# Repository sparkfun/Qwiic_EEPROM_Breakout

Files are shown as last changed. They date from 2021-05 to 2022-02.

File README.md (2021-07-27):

Qwiic EEPROM - 512Kbit
=======================================

Qwiic EEPROM

[*Qwiic EEPROM - 512Kbit (COM-18355)*](https://www.sparkfun.com/products/18355)

A simple breakout for the 512kbit common I2C EEPROMs.

Repository Contents
-------------------

* **/Hardware** - Eagle design files (.brd, .sch)
* **/Firmware** - EEPROM test sketch

Documentation
------------

* **[SparkFun External EEPROM Arduino Library](https://github.com/sparkfun/SparkFun_External_EEPROM_Arduino_Library)** - Arduino library for the Qwiic EEPROM - 512Kbit
* **[Qwiic EEPROM Python Package](https://github.com/sparkfun/Qwiic_EEPROM_Py)** - Python package for the Qwiic EEPROM - 512Kbit
* **[Datasheet CAT24C512](https://www.onsemi.com/pub/Collateral/CAT24C512-D.PDF)** - Datasheet for EEPROM part number 24512A
* **[Reading and Writing Serial EEPROMs](https://learn.sparkfun.com/tutorials/reading-and-writing-serial-eeproms)** - Tutorial
* **[Qwiic EEPROM Hookup Guide](https://learn.sparkfun.com/tutorials/1661)** - Hookup guide for the Qwiic EEPROM - 512Kbit

<!-- * **[Datasheet RM24C512C](https://cdn.sparkfun.com/assets/2/c/4/c/0/DS-RM24C512C_082.pdf)** - Datasheet for EEPROM part number 24512C -->

License Information
-------------------

This product is _**open source**_! 

Please review the LICENSE.md file for license information. 

If you have any questions or concerns on licensing, please contact technical support on our [SparkFun forums](https://forum.sparkfun.com/viewforum.php?f=152).

Distributed as-is; no warranty is given.

- Your friends at SparkFun.

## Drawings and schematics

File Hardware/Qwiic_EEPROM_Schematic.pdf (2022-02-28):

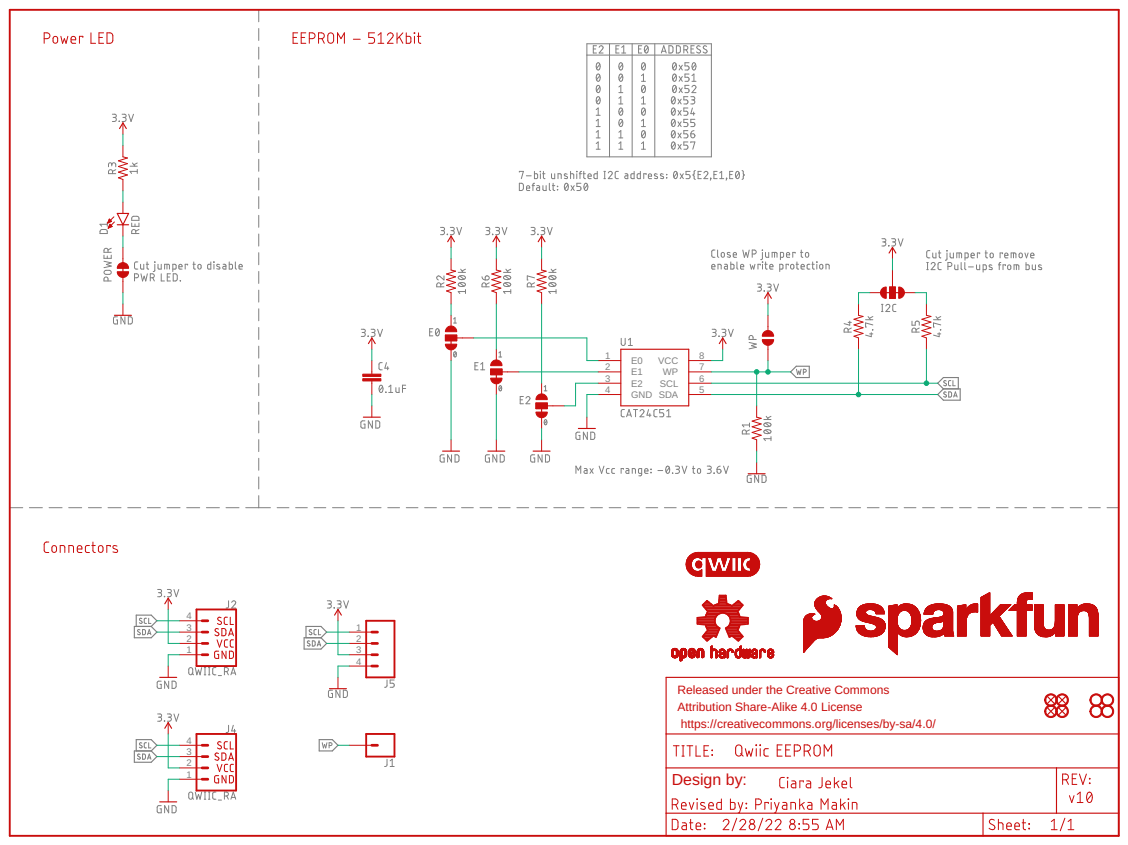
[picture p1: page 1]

https://creativecommons.org/licenses/by-sa/4.0/

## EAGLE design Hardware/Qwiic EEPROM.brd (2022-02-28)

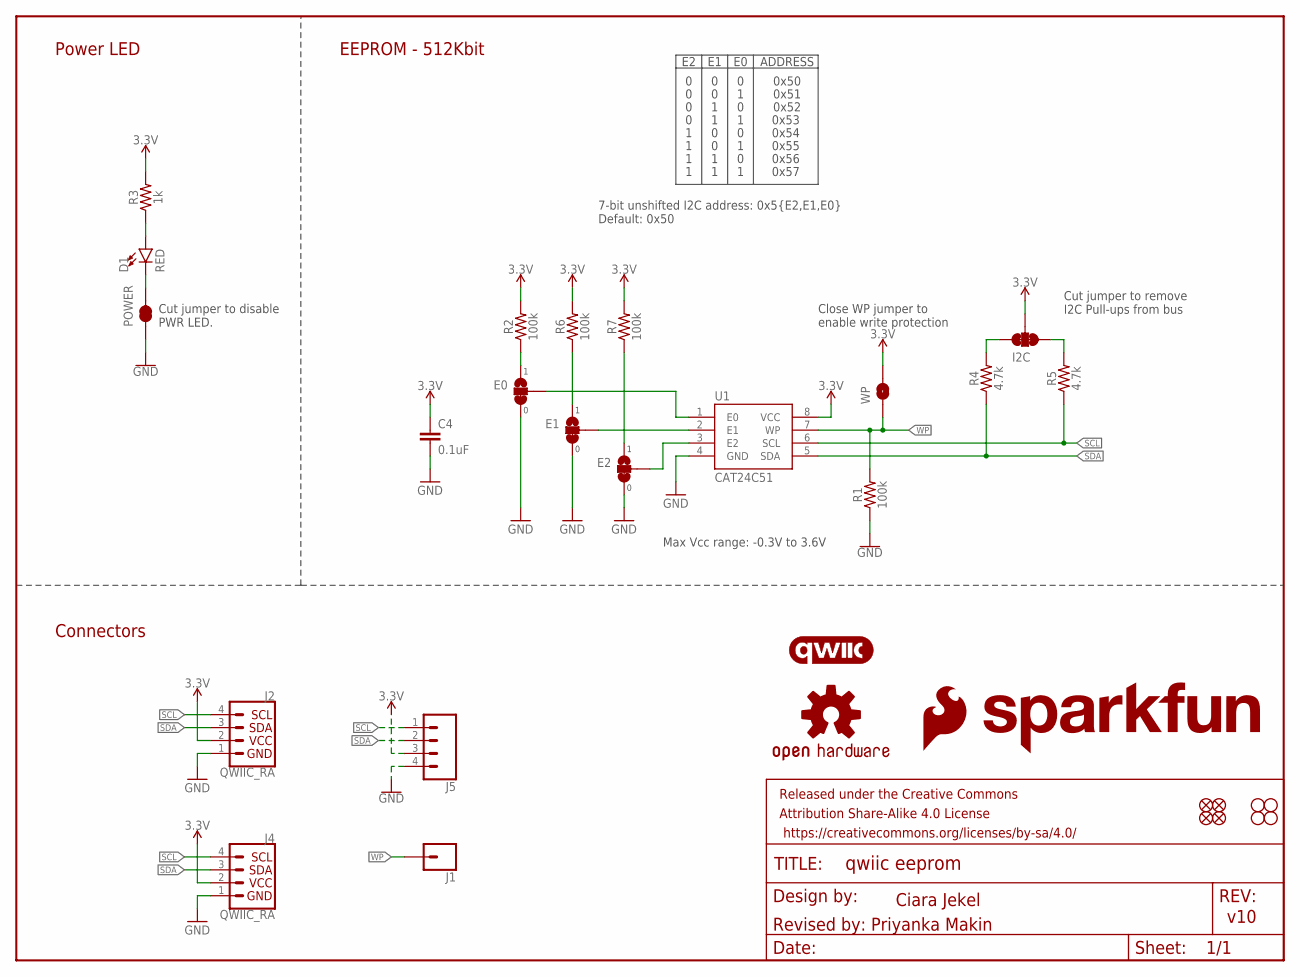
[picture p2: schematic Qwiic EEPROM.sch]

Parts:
C4: 0.1uF; 0603
D1: RED; LED-0603
E0, E1, E2: JUMPER-SMT_3_1-NC_TRACE_SILK; SMT-JUMPER_3_1-NC_TRACE_SILK
FRAME1: FRAME-LETTER; CREATIVE_COMMONS
I2C: JUMPER-SMT_3_2-NC_TRACE_SILK; SMT-JUMPER_3_2-NC_TRACE_SILK
J1: CONN_01PTH_NO_SILK_YES_STOP; 1X01_NO_SILK
J2, J4: QWIIC_RA; JST04_1MM_RA
J5: CONN_041X04_NO_SILK_NO_POP; 1X04_NO_SILK
JP1, JP2, JP5, JP6: FIDUCIALUFIDUCIAL; FIDUCIAL-MICRO
JP3, JP4, JP7, JP8: STAND-OFF
LOGO1: OSHW-LOGOMINI; OSHW-LOGO-MINI
LOGO2: SFE_LOGO_NAME.1_INCH; SFE_LOGO_NAME_.1
LOGO3: SFE_LOGO_FLAME.1_INCH; SFE_LOGO_FLAME_.1
LOGO4: QWIIC_LOGO_4MM; QWIIC_4MM
POWER: JUMPER-SMT_2_NC_TRACE_SILK; SMT-JUMPER_2_NC_TRACE_SILK
R1, R2, R6, R7: 100k; 0603
R3: 1k; 0603
R4, R5: 4.7k; 0603
U1: CAT24C51; SO08
WP: JUMPER-SMT_2_NO_SILK; SMT-JUMPER_2_NO_SILK

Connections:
3.3V: C4.1, I2C.2, J2.2, J4.2, J5.3, R2.2, R3.2, R6.2, R7.2, U1.8 (VCC), WP.2
GND: C4.2, E0.3, E1.3, E2.3, J2.1, J4.1, J5.4, POWER.1, R1.1, U1.4 (GND)
unnamed: I2C.1, R5.2
unnamed: I2C.3, R4.2
unnamed: D1.A, R3.1
unnamed: E2.2, U1.3 (E2)
unnamed: E1.2, U1.2 (E1)
unnamed: E0.2, U1.1 (E0)
unnamed: E0.1, R2.1
unnamed: E2.1, R7.1
unnamed: E1.1, R6.1
unnamed: D1.C, POWER.2
SCL: J2.4, J4.4, J5.1, R5.1, U1.6 (SCL)
SDA: J2.3, J4.3, J5.2, R4.1, U1.5 (SDA)
WP: J1.1, R1.2, U1.7 (WP), WP.1

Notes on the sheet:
Ciara Jekel
v10
7-bit unshifted I2C address: 0x5{E2,E1,E0} Default: 0x50
Cut jumper to remove I2C Pull-ups from bus
Close WP jumper to enable write protection
ADDRESS
0x50
0x51
0x52
0x53
0x54
0x55
0x56
0x57
Revised by: Priyanka Makin
Power LED
EEPROM - 512Kbit
Connectors
Max Vcc range: -0.3V to 3.6V
Cut jumper to disable PWR LED.

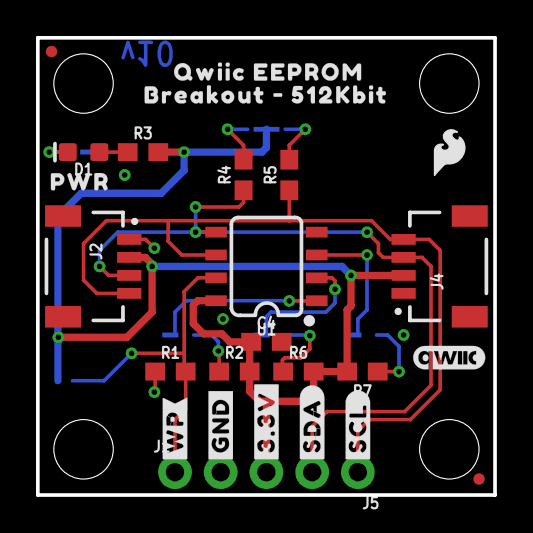
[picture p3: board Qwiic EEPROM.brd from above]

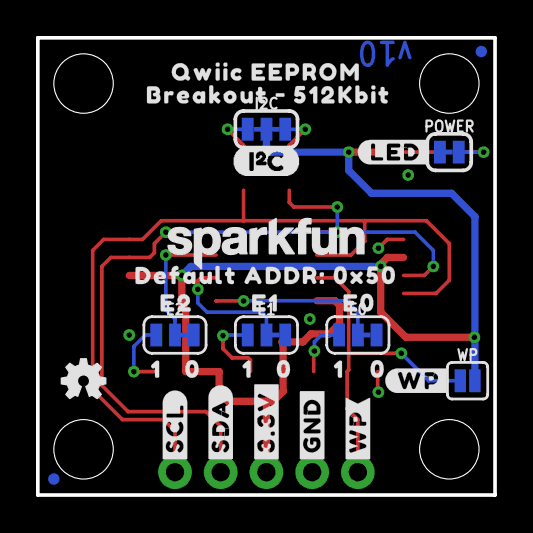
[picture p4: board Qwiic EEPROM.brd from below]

Board: 2 copper layers, 25.4 x 25.4 mm, 61 parts (30 on the bottom side), 15 nets.

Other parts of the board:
U$1, U$2: #WP#3
U$3: #WP#0
U$4: E00
U$5: E10
U$6: E20
U$7, U$8, U$9: 00
U$10, U$14: #GND#0
U$11: (I_SUPER2_C)
U$12: PWR0
U$13, U$21, U$22: 10
U$15, U$16: #3#3V#0
U$17, U$29: #SDA#0
U$18: #LED#2
U$19, U$20: QWIIC_EEPROM0
U$23, U$24: BREAKOUT_#_512KBIT0
U$25: DEFAULT_ADDR#_0X500
U$30, U$31: #SCL#0

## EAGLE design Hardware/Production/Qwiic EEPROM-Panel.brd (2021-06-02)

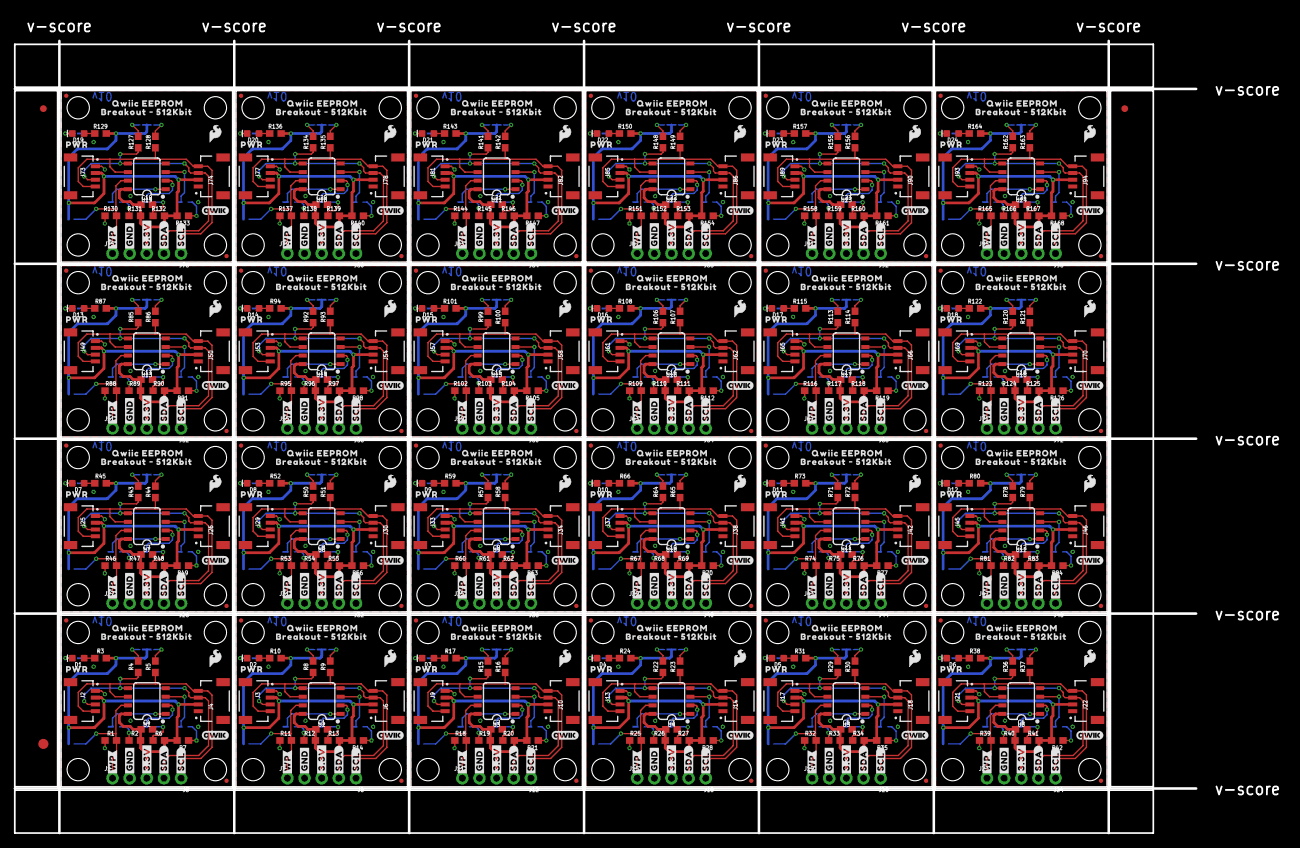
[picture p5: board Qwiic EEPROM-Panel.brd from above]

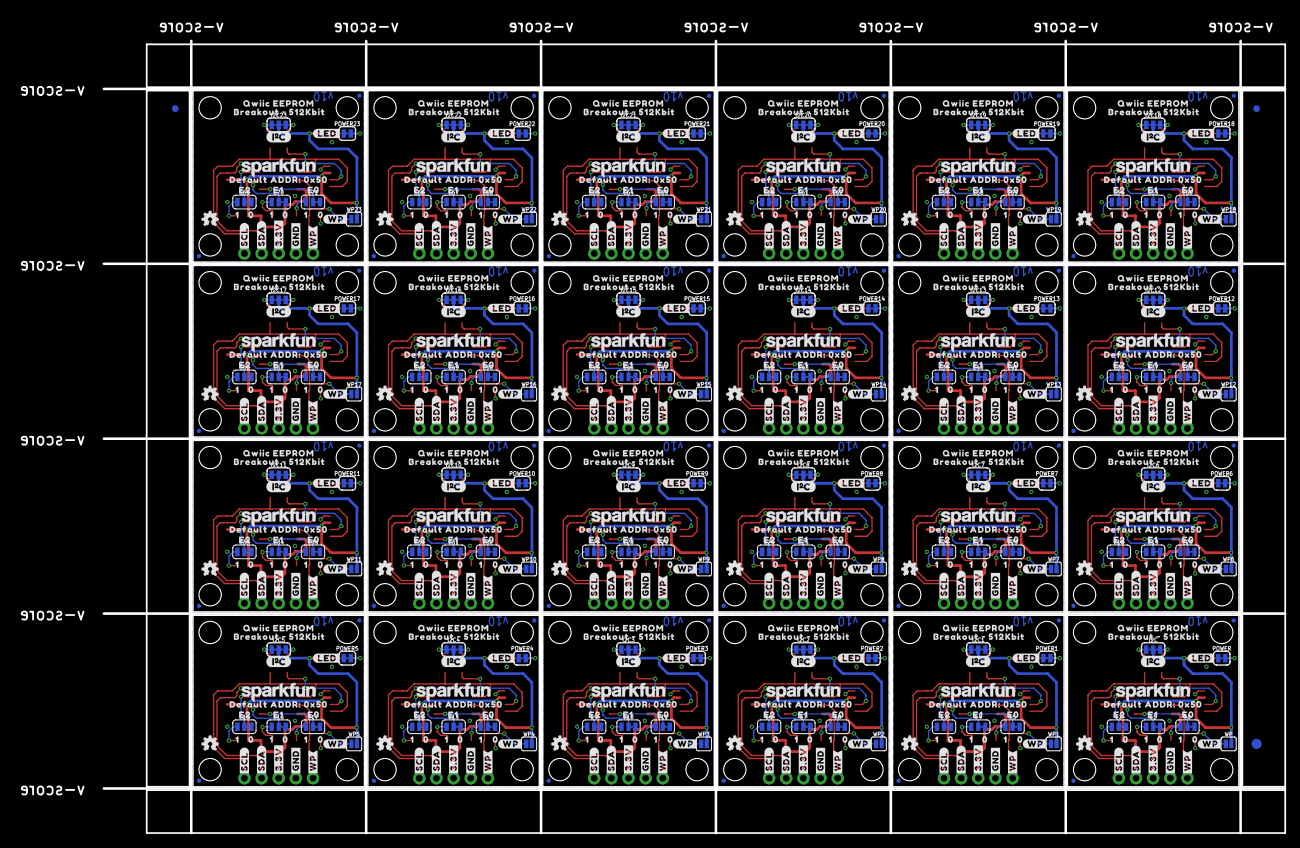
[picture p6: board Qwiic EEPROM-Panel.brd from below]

Board: 2 copper layers, 175.0 x 117.3 mm, 1446 parts (723 on the bottom side), 360 nets.

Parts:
C1, C2, C3, C4, C5, C6, C7, C8, C9, C10, C11, C12, C13, C14, C15, C16, C17, C18, C19, C20, C21, C22, C23, C24: 0.1uF; 0603
D1, D2, D3, D4, D5, D6, D7, D8, D9, D10, D11, D12, D13, D14, D15, D16, D17, D18, D19, D20, D21, D22, D23, D24: RED; LED-0603
E0, E1, E2, E3, E4, E5, E6, E7, E8, E9, E10, E11, E12, E13, E14, E15, E16, E17, E18, E19, E20, E21, E22, E23, E24, E25, E26, E27, E28, E29, E30, E31, E32, E33, E34, E35, E36, E37, E38, E39, E40, E41, E42, E43, E44, E45, E46, E47, E48, E49, E50, E51, E52, E53, E54, E55, E56, E57, E58, E59, E60, E61, E62, E63, E64, E65, E66, E67, E68, E69, E70, E71: JUMPER-SMT_3_1-NC_TRACE_SILK; SMT-JUMPER_3_1-NC_TRACE_SILK
E$1, E$2, E$3, E$4: FIDUCIAL-1X2
E$5, E$6: FIDUCIAL-1.5X3
I2C, I2C1, I2C2, I2C3, I2C4, I2C5, I2C6, I2C7, I2C8, I2C9, I2C10, I2C11, I2C12, I2C13, I2C14, I2C15, I2C16, I2C17, I2C18, I2C19, I2C20, I2C21, I2C22, I2C23: JUMPER-SMT_3_2-NC_TRACE_SILK; SMT-JUMPER_3_2-NC_TRACE_SILK
J1, J7, J11, J15, J19, J23, J27, J31, J35, J39, J43, J47, J51, J55, J59, J63, J67, J71, J75, J79, J83, J87, J91, J95: 1X01_NO_SILK
J2, J3, J4, J6, J9, J10, J13, J14, J17, J18, J21, J22, J25, J26, J29, J30, J33, J34, J37, J38, J41, J42, J45, J46, J49, J50, J53, J54, J57, J58, J61, J62, J65, J66, J69, J70, J73, J74, J77, J78, J81, J82, J85, J86, J89, J90, J93, J94: QWIIC_RA; JST04_1MM_RA
J5, J8, J12, J16, J20, J24, J28, J32, J36, J40, J44, J48, J52, J56, J60, J64, J68, J72, J76, J80, J84, J88, J92, J96: 1X04_NO_SILK
JP1, JP2, JP5, JP6, JP11, JP12, JP13, JP14, JP19, JP20, JP21, JP22, JP27, JP28, JP29, JP30, JP35, JP36, JP37, JP38, JP43, JP44, JP45, JP46, JP51, JP52, JP53, JP54, JP59, JP60, JP61, JP62, JP67, JP68, JP69, JP70, JP75, JP76, JP77, JP78, JP83, JP84, JP85, JP86, JP91, JP92, JP93, JP94, JP99, JP100, JP101, JP102, JP107, JP108, JP109, JP110, JP115, JP116, JP117, JP118, JP123, JP124, JP125, JP126, JP131, JP132, JP133, JP134, JP139, JP140, JP141, JP142, JP147, JP148, JP149, JP150, JP155, JP156, JP157, JP158, JP163, JP164, JP165, JP166, JP171, JP172, JP173, JP174, JP179, JP180, JP181, JP182, JP187, JP188, JP189, JP190: FIDUCIALUFIDUCIAL; FIDUCIAL-MICRO
JP3, JP4, JP7, JP8, JP9, JP10, JP15, JP16, JP17, JP18, JP23, JP24, JP25, JP26, JP31, JP32, JP33, JP34, JP39, JP40, JP41, JP42, JP47, JP48, JP49, JP50, JP55, JP56, JP57, JP58, JP63, JP64, JP65, JP66, JP71, JP72, JP73, JP74, JP79, JP80, JP81, JP82, JP87, JP88, JP89, JP90, JP95, JP96, JP97, JP98, JP103, JP104, JP105, JP106, JP111, JP112, JP113, JP114, JP119, JP120, JP121, JP122, JP127, JP128, JP129, JP130, JP135, JP136, JP137, JP138, JP143, JP144, JP145, JP146, JP151, JP152, JP153, JP154, JP159, JP160, JP161, JP162, JP167, JP168, JP169, JP170, JP175, JP176, JP177, JP178, JP183, JP184, JP185, JP186, JP191, JP192: STAND-OFF
LOGO1, LOGO5, LOGO9, LOGO13, LOGO17, LOGO21, LOGO25, LOGO29, LOGO33, LOGO37, LOGO41, LOGO45, LOGO49, LOGO53, LOGO57, LOGO61, LOGO65, LOGO69, LOGO73, LOGO77, LOGO81, LOGO85, LOGO89, LOGO93: OSHW-LOGOMINI; OSHW-LOGO-MINI
LOGO2, LOGO6, LOGO10, LOGO14, LOGO18, LOGO22, LOGO26, LOGO30, LOGO34, LOGO38, LOGO42, LOGO46, LOGO50, LOGO54, LOGO58, LOGO62, LOGO66, LOGO70, LOGO74, LOGO78, LOGO82, LOGO86, LOGO90, LOGO94: SFE_LOGO_NAME.1_INCH; SFE_LOGO_NAME_.1
LOGO3, LOGO7, LOGO11, LOGO15, LOGO19, LOGO23, LOGO27, LOGO31, LOGO35, LOGO39, LOGO43, LOGO47, LOGO51, LOGO55, LOGO59, LOGO63, LOGO67, LOGO71, LOGO75, LOGO79, LOGO83, LOGO87, LOGO91, LOGO95: SFE_LOGO_FLAME.1_INCH; SFE_LOGO_FLAME_.1
LOGO4, LOGO8, LOGO12, LOGO16, LOGO20, LOGO24, LOGO28, LOGO32, LOGO36, LOGO40, LOGO44, LOGO48, LOGO52, LOGO56, LOGO60, LOGO64, LOGO68, LOGO72, LOGO76, LOGO80, LOGO84, LOGO88, LOGO92, LOGO96: QWIIC_LOGO_4MM; QWIIC_4MM
POWER, POWER1, POWER2, POWER3, POWER4, POWER5, POWER6, POWER7, POWER8, POWER9, POWER10, POWER11, POWER12, POWER13, POWER14, POWER15, POWER16, POWER17, POWER18, POWER19, POWER20, POWER21, POWER22, POWER23: JUMPER-SMT_2_NC_TRACE_SILK; SMT-JUMPER_2_NC_TRACE_SILK
R1, R2, R6, R7, R11, R12, R13, R14, R18, R19, R20, R21, R25, R26, R27, R28, R32, R33, R34, R35, R39, R40, R41, R42, R46, R47, R48, R49, R53, R54, R55, R56, R60, R61, R62, R63, R67, R68, R69, R70, R74, R75, R76, R77, R81, R82, R83, R84, R88, R89, R90, R91, R95, R96, R97, R98, R102, R103, R104, R105, R109, R110, R111, R112, R116, R117, R118, R119, R123, R124, R125, R126, R130, R131, R132, R133, R137, R138, R139, R140, R144, R145, R146, R147, R151, R152, R153, R154, R158, R159, R160, R161, R165, R166, R167, R168: 100k; 0603
R3, R10, R17, R24, R31, R38, R45, R52, R59, R66, R73, R80, R87, R94, R101, R108, R115, R122, R129, R136, R143, R150, R157, R164: 1k; 0603
R4, R5, R8, R9, R15, R16, R22, R23, R29, R30, R36, R37, R43, R44, R50, R51, R57, R58, R64, R65, R71, R72, R78, R79, R85, R86, R92, R93, R99, R100, R106, R107, R113, R114, R120, R121, R127, R128, R134, R135, R141, R142, R148, R149, R155, R156, R162, R163: 4.7k; 0603
U1, U2, U3, U4, U5, U6, U7, U8, U9, U10, U11, U12, U13, U14, U15, U16, U17, U18, U19, U20, U21, U22, U23, U24: RM24C512C; SO08
U$1, U$2, U$54, U$55, U$82, U$83, U$110, U$111, U$138, U$139, U$166, U$167, U$194, U$195, U$222, U$223, U$250, U$251, U$278, U$279, U$306, U$307, U$334, U$335, U$362, U$363, U$390, U$391, U$418, U$419, U$446, U$447, U$474, U$475, U$502, U$503, U$530, U$531, U$558, U$559, U$586, U$587, U$614, U$615, U$642, U$643, U$670, U$671: #WP#3
U$3, U$52, U$80, U$108, U$136, U$164, U$192, U$220, U$248, U$276, U$304, U$332, U$360, U$388, U$416, U$444, U$472, U$500, U$528, U$556, U$584, U$612, U$640, U$668: #WP#0
U$4, U$38, U$66, U$94, U$122, U$150, U$178, U$206, U$234, U$262, U$290, U$318, U$346, U$374, U$402, U$430, U$458, U$486, U$514, U$542, U$570, U$598, U$626, U$654: E00
U$5, U$39, U$67, U$95, U$123, U$151, U$179, U$207, U$235, U$263, U$291, U$319, U$347, U$375, U$403, U$431, U$459, U$487, U$515, U$543, U$571, U$599, U$627, U$655: E10
U$6, U$40, U$68, U$96, U$124, U$152, U$180, U$208, U$236, U$264, U$292, U$320, U$348, U$376, U$404, U$432, U$460, U$488, U$516, U$544, U$572, U$600, U$628, U$656: E20
U$7, U$8, U$9, U$41, U$42, U$43, U$69, U$70, U$71, U$97, U$98, U$99, U$125, U$126, U$127, U$153, U$154, U$155, U$181, U$182, U$183, U$209, U$210, U$211, U$237, U$238, U$239, U$265, U$266, U$267, U$293, U$294, U$295, U$321, U$322, U$323, U$349, U$350, U$351, U$377, U$378, U$379, U$405, U$406, U$407, U$433, U$434, U$435, U$461, U$462, U$463, U$489, U$490, U$491, U$517, U$518, U$519, U$545, U$546, U$547, U$573, U$574, U$575, U$601, U$602, U$603, U$629, U$630, U$631, U$657, U$658, U$659: 00
U$10, U$14, U$27, U$28, U$58, U$59, U$86, U$87, U$114, U$115, U$142, U$143, U$170, U$171, U$198, U$199, U$226, U$227, U$254, U$255, U$282, U$283, U$310, U$311, U$338, U$339, U$366, U$367, U$394, U$395, U$422, U$423, U$450, U$451, U$478, U$479, U$506, U$507, U$534, U$535, U$562, U$563, U$590, U$591, U$618, U$619, U$646, U$647: #GND#0
U$11, U$26, U$57, U$85, U$113, U$141, U$169, U$197, U$225, U$253, U$281, U$309, U$337, U$365, U$393, U$421, U$449, U$477, U$505, U$533, U$561, U$589, U$617, U$645: (I_SUPER2_C)
U$12, U$47, U$75, U$103, U$131, U$159, U$187, U$215, U$243, U$271, U$299, U$327, U$355, U$383, U$411, U$439, U$467, U$495, U$523, U$551, U$579, U$607, U$635, U$663: PWR0
U$13, U$21, U$22, U$44, U$45, U$46, U$72, U$73, U$74, U$100, U$101, U$102, U$128, U$129, U$130, U$156, U$157, U$158, U$184, U$185, U$186, U$212, U$213, U$214, U$240, U$241, U$242, U$268, U$269, U$270, U$296, U$297, U$298, U$324, U$325, U$326, U$352, U$353, U$354, U$380, U$381, U$382, U$408, U$409, U$410, U$436, U$437, U$438, U$464, U$465, U$466, U$492, U$493, U$494, U$520, U$521, U$522, U$548, U$549, U$550, U$576, U$577, U$578, U$604, U$605, U$606, U$632, U$633, U$634, U$660, U$661, U$662: 10
U$15, U$16, U$32, U$33, U$60, U$61, U$88, U$89, U$116, U$117, U$144, U$145, U$172, U$173, U$200, U$201, U$228, U$229, U$256, U$257, U$284, U$285, U$312, U$313, U$340, U$341, U$368, U$369, U$396, U$397, U$424, U$425, U$452, U$453, U$480, U$481, U$508, U$509, U$536, U$537, U$564, U$565, U$592, U$593, U$620, U$621, U$648, U$649: #3#3V#0
U$17, U$29, U$34, U$35, U$62, U$63, U$90, U$91, U$118, U$119, U$146, U$147, U$174, U$175, U$202, U$203, U$230, U$231, U$258, U$259, U$286, U$287, U$314, U$315, U$342, U$343, U$370, U$371, U$398, U$399, U$426, U$427, U$454, U$455, U$482, U$483, U$510, U$511, U$538, U$539, U$566, U$567, U$594, U$595, U$622, U$623, U$650, U$651: #SDA#0
U$18, U$53, U$81, U$109, U$137, U$165, U$193, U$221, U$249, U$277, U$305, U$333, U$361, U$389, U$417, U$445, U$473, U$501, U$529, U$557, U$585, U$613, U$641, U$669: #LED#2
U$19, U$20, U$48, U$49, U$76, U$77, U$104, U$105, U$132, U$133, U$160, U$161, U$188, U$189, U$216, U$217, U$244, U$245, U$272, U$273, U$300, U$301, U$328, U$329, U$356, U$357, U$384, U$385, U$412, U$413, U$440, U$441, U$468, U$469, U$496, U$497, U$524, U$525, U$552, U$553, U$580, U$581, U$608, U$609, U$636, U$637, U$664, U$665: QWIIC_EEPROM0
U$23, U$24, U$50, U$51, U$78, U$79, U$106, U$107, U$134, U$135, U$162, U$163, U$190, U$191, U$218, U$219, U$246, U$247, U$274, U$275, U$302, U$303, U$330, U$331, U$358, U$359, U$386, U$387, U$414, U$415, U$442, U$443, U$470, U$471, U$498, U$499, U$526, U$527, U$554, U$555, U$582, U$583, U$610, U$611, U$638, U$639, U$666, U$667: BREAKOUT_#_512KBIT0
U$25, U$56, U$84, U$112, U$140, U$168, U$196, U$224, U$252, U$280, U$308, U$336, U$364, U$392, U$420, U$448, U$476, U$504, U$532, U$560, U$588, U$616, U$644, U$672: DEFAULT_ADDR#_0X500
U$30, U$31, U$36, U$37, U$64, U$65, U$92, U$93, U$120, U$121, U$148, U$149, U$176, U$177, U$204, U$205, U$232, U$233, U$260, U$261, U$288, U$289, U$316, U$317, U$344, U$345, U$372, U$373, U$400, U$401, U$428, U$429, U$456, U$457, U$484, U$485, U$512, U$513, U$540, U$541, U$568, U$569, U$596, U$597, U$624, U$625, U$652, U$653: #SCL#0
WP, WP1, WP2, WP3, WP4, WP5, WP6, WP7, WP8, WP9, WP10, WP11, WP12, WP13, WP14, WP15, WP16, WP17, WP18, WP19, WP20, WP21, WP22, WP23: JUMPER-SMT_2_NO_SILK; SMT-JUMPER_2_NO_SILK

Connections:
3.3V: C4.1, I2C.2, J2.2, J4.2, J5.3, R2.2, R3.2, R6.2, R7.2, U1.8, WP.2
3.3V1: C1.1, I2C1.2, J3.2, J6.2, J8.3, R10.2, R12.2, R13.2, R14.2, U2.8, WP1.2
3.3V2: C2.1, I2C2.2, J9.2, J10.2, J12.3, R17.2, R19.2, R20.2, R21.2, U3.8, WP2.2
3.3V3: C3.1, I2C3.2, J13.2, J14.2, J16.3, R24.2, R26.2, R27.2, R28.2, U4.8, WP3.2
3.3V4: C5.1, I2C4.2, J17.2, J18.2, J20.3, R31.2, R33.2, R34.2, R35.2, U5.8, WP4.2
3.3V5: C6.1, I2C5.2, J21.2, J22.2, J24.3, R38.2, R40.2, R41.2, R42.2, U6.8, WP5.2
3.3V6: C7.1, I2C6.2, J25.2, J26.2, J28.3, R45.2, R47.2, R48.2, R49.2, U7.8, WP6.2
3.3V7: C8.1, I2C7.2, J29.2, J30.2, J32.3, R52.2, R54.2, R55.2, R56.2, U8.8, WP7.2
3.3V8: C9.1, I2C8.2, J33.2, J34.2, J36.3, R59.2, R61.2, R62.2, R63.2, U9.8, WP8.2
3.3V9: C10.1, I2C9.2, J37.2, J38.2, J40.3, R66.2, R68.2, R69.2, R70.2, U10.8, WP9.2
3.3V10: C11.1, I2C10.2, J41.2, J42.2, J44.3, R73.2, R75.2, R76.2, R77.2, U11.8, WP10.2
3.3V11: C12.1, I2C11.2, J45.2, J46.2, J48.3, R80.2, R82.2, R83.2, R84.2, U12.8, WP11.2
3.3V12: C13.1, I2C12.2, J49.2, J50.2, J52.3, R87.2, R89.2, R90.2, R91.2, U13.8, WP12.2
3.3V13: C14.1, I2C13.2, J53.2, J54.2, J56.3, R94.2, R96.2, R97.2, R98.2, U14.8, WP13.2
3.3V14: C15.1, I2C14.2, J57.2, J58.2, J60.3, R101.2, R103.2, R104.2, R105.2, U15.8, WP14.2
3.3V15: C16.1, I2C15.2, J61.2, J62.2, J64.3, R108.2, R110.2, R111.2, R112.2, U16.8, WP15.2
3.3V16: C17.1, I2C16.2, J65.2, J66.2, J68.3, R115.2, R117.2, R118.2, R119.2, U17.8, WP16.2
3.3V17: C18.1, I2C17.2, J69.2, J70.2, J72.3, R122.2, R124.2, R125.2, R126.2, U18.8, WP17.2
3.3V18: C19.1, I2C18.2, J73.2, J74.2, J76.3, R129.2, R131.2, R132.2, R133.2, U19.8, WP18.2
3.3V19: C20.1, I2C19.2, J77.2, J78.2, J80.3, R136.2, R138.2, R139.2, R140.2, U20.8, WP19.2
3.3V20: C21.1, I2C20.2, J81.2, J82.2, J84.3, R143.2, R145.2, R146.2, R147.2, U21.8, WP20.2
3.3V21: C22.1, I2C21.2, J85.2, J86.2, J88.3, R150.2, R152.2, R153.2, R154.2, U22.8, WP21.2
3.3V22: C23.1, I2C22.2, J89.2, J90.2, J92.3, R157.2, R159.2, R160.2, R161.2, U23.8, WP22.2
3.3V23: C24.1, I2C23.2, J93.2, J94.2, J96.3, R164.2, R166.2, R167.2, R168.2, U24.8, WP23.2
GND: C4.2, E0.3, E1.3, E2.3, J2.1, J4.1, J5.4, POWER.1, R1.1, U1.4
GND1: C1.2, E3.3, E4.3, E5.3, J3.1, J6.1, J8.4, POWER1.1, R11.1, U2.4
GND2: C2.2, E6.3, E7.3, E8.3, J9.1, J10.1, J12.4, POWER2.1, R18.1, U3.4
GND3: C3.2, E9.3, E10.3, E11.3, J13.1, J14.1, J16.4, POWER3.1, R25.1, U4.4
GND4: C5.2, E12.3, E13.3, E14.3, J17.1, J18.1, J20.4, POWER4.1, R32.1, U5.4
GND5: C6.2, E15.3, E16.3, E17.3, J21.1, J22.1, J24.4, POWER5.1, R39.1, U6.4
GND6: C7.2, E18.3, E19.3, E20.3, J25.1, J26.1, J28.4, POWER6.1, R46.1, U7.4
GND7: C8.2, E21.3, E22.3, E23.3, J29.1, J30.1, J32.4, POWER7.1, R53.1, U8.4
GND8: C9.2, E24.3, E25.3, E26.3, J33.1, J34.1, J36.4, POWER8.1, R60.1, U9.4
GND9: C10.2, E27.3, E28.3, E29.3, J37.1, J38.1, J40.4, POWER9.1, R67.1, U10.4
GND10: C11.2, E30.3, E31.3, E32.3, J41.1, J42.1, J44.4, POWER10.1, R74.1, U11.4
GND11: C12.2, E33.3, E34.3, E35.3, J45.1, J46.1, J48.4, POWER11.1, R81.1, U12.4
GND12: C13.2, E36.3, E37.3, E38.3, J49.1, J50.1, J52.4, POWER12.1, R88.1, U13.4
GND13: C14.2, E39.3, E40.3, E41.3, J53.1, J54.1, J56.4, POWER13.1, R95.1, U14.4
GND14: C15.2, E42.3, E43.3, E44.3, J57.1, J58.1, J60.4, POWER14.1, R102.1, U15.4
GND15: C16.2, E45.3, E46.3, E47.3, J61.1, J62.1, J64.4, POWER15.1, R109.1, U16.4
GND16: C17.2, E48.3, E49.3, E50.3, J65.1, J66.1, J68.4, POWER16.1, R116.1, U17.4
GND17: C18.2, E51.3, E52.3, E53.3, J69.1, J70.1, J72.4, POWER17.1, R123.1, U18.4
GND18: C19.2, E54.3, E55.3, E56.3, J73.1, J74.1, J76.4, POWER18.1, R130.1, U19.4
GND19: C20.2, E57.3, E58.3, E59.3, J77.1, J78.1, J80.4, POWER19.1, R137.1, U20.4
GND20: C21.2, E60.3, E61.3, E62.3, J81.1, J82.1, J84.4, POWER20.1, R144.1, U21.4
GND21: C22.2, E63.3, E64.3, E65.3, J85.1, J86.1, J88.4, POWER21.1, R151.1, U22.4
GND22: C23.2, E66.3, E67.3, E68.3, J89.1, J90.1, J92.4, POWER22.1, R158.1, U23.4
GND23: C24.2, E69.3, E70.3, E71.3, J93.1, J94.1, J96.4, POWER23.1, R165.1, U24.4
unnamed: I2C.1, R5.2
unnamed: I2C.3, R4.2
unnamed: D1.A, R3.1
unnamed: E2.2, U1.3
unnamed: E1.2, U1.2
unnamed: E0.2, U1.1
unnamed: E0.1, R2.1
unnamed: E2.1, R7.1
unnamed: E1.1, R6.1
unnamed: D1.C, POWER.2
unnamed: I2C1.1, R9.2
unnamed: I2C1.3, R8.2
unnamed: D2.A, R10.1
unnamed: E4.2, U2.2
unnamed: E5.1, R12.1
unnamed: E3.1, R14.1
unnamed: E4.1, R13.1
unnamed: E5.2, U2.1
unnamed: E3.2, U2.3
unnamed: D2.C, POWER1.2
unnamed: I2C2.1, R16.2
unnamed: I2C2.3, R15.2
unnamed: D3.A, R17.1
unnamed: E7.2, U3.2
unnamed: E8.1, R19.1
unnamed: E6.1, R21.1
unnamed: E7.1, R20.1
unnamed: E8.2, U3.1
unnamed: E6.2, U3.3
unnamed: D3.C, POWER2.2
unnamed: I2C3.1, R23.2
unnamed: I2C3.3, R22.2
unnamed: D4.A, R24.1
unnamed: E10.2, U4.2
unnamed: E11.1, R26.1
unnamed: E9.1, R28.1
unnamed: E10.1, R27.1
unnamed: E11.2, U4.1
unnamed: E9.2, U4.3
unnamed: D4.C, POWER3.2
unnamed: I2C4.1, R30.2
unnamed: I2C4.3, R29.2
unnamed: D5.A, R31.1
unnamed: E13.2, U5.2
unnamed: E14.1, R33.1
unnamed: E12.1, R35.1
unnamed: E13.1, R34.1
unnamed: E14.2, U5.1
unnamed: E12.2, U5.3
unnamed: D5.C, POWER4.2
unnamed: I2C5.1, R37.2
unnamed: I2C5.3, R36.2
unnamed: D6.A, R38.1
unnamed: E16.2, U6.2
unnamed: E17.1, R40.1
unnamed: E15.1, R42.1
unnamed: E16.1, R41.1
unnamed: E17.2, U6.1
unnamed: E15.2, U6.3
unnamed: D6.C, POWER5.2
unnamed: I2C6.1, R44.2
unnamed: I2C6.3, R43.2
unnamed: D7.A, R45.1
unnamed: E19.2, U7.2
unnamed: E20.1, R47.1
unnamed: E18.1, R49.1
unnamed: E19.1, R48.1
unnamed: E20.2, U7.1
unnamed: E18.2, U7.3
unnamed: D7.C, POWER6.2
unnamed: I2C7.1, R51.2
unnamed: I2C7.3, R50.2
unnamed: D8.A, R52.1
unnamed: E22.2, U8.2
unnamed: E23.1, R54.1
unnamed: E21.1, R56.1
unnamed: E22.1, R55.1
unnamed: E23.2, U8.1
unnamed: E21.2, U8.3
unnamed: D8.C, POWER7.2
unnamed: I2C8.1, R58.2
unnamed: I2C8.3, R57.2
unnamed: D9.A, R59.1
unnamed: E25.2, U9.2
unnamed: E26.1, R61.1
unnamed: E24.1, R63.1
unnamed: E25.1, R62.1
unnamed: E26.2, U9.1
unnamed: E24.2, U9.3
unnamed: D9.C, POWER8.2
unnamed: I2C9.1, R65.2
unnamed: I2C9.3, R64.2
unnamed: D10.A, R66.1
unnamed: E28.2, U10.2
unnamed: E29.1, R68.1
unnamed: E27.1, R70.1
unnamed: E28.1, R69.1
unnamed: E29.2, U10.1
unnamed: E27.2, U10.3
unnamed: D10.C, POWER9.2
unnamed: I2C10.1, R72.2
unnamed: I2C10.3, R71.2
unnamed: D11.A, R73.1
unnamed: E31.2, U11.2
unnamed: E32.1, R75.1
unnamed: E30.1, R77.1
unnamed: E31.1, R76.1
unnamed: E32.2, U11.1
unnamed: E30.2, U11.3
unnamed: D11.C, POWER10.2
unnamed: I2C11.1, R79.2
unnamed: I2C11.3, R78.2
unnamed: D12.A, R80.1
unnamed: E34.2, U12.2
unnamed: E35.1, R82.1
unnamed: E33.1, R84.1
unnamed: E34.1, R83.1
unnamed: E35.2, U12.1
unnamed: E33.2, U12.3
unnamed: D12.C, POWER11.2
unnamed: I2C12.1, R86.2
unnamed: I2C12.3, R85.2
unnamed: D13.A, R87.1
unnamed: E37.2, U13.2
unnamed: E38.1, R89.1
unnamed: E36.1, R91.1
unnamed: E37.1, R90.1
unnamed: E38.2, U13.1
unnamed: E36.2, U13.3
unnamed: D13.C, POWER12.2
unnamed: I2C13.1, R93.2
unnamed: I2C13.3, R92.2
unnamed: D14.A, R94.1
unnamed: E40.2, U14.2
unnamed: E41.1, R96.1
unnamed: E39.1, R98.1
unnamed: E40.1, R97.1
unnamed: E41.2, U14.1
unnamed: E39.2, U14.3
unnamed: D14.C, POWER13.2
unnamed: I2C14.1, R100.2
unnamed: I2C14.3, R99.2
unnamed: D15.A, R101.1
unnamed: E43.2, U15.2
unnamed: E44.1, R103.1
unnamed: E42.1, R105.1
unnamed: E43.1, R104.1
unnamed: E44.2, U15.1
unnamed: E42.2, U15.3
unnamed: D15.C, POWER14.2
unnamed: I2C15.1, R107.2
unnamed: I2C15.3, R106.2
unnamed: D16.A, R108.1
unnamed: E46.2, U16.2
unnamed: E47.1, R110.1
unnamed: E45.1, R112.1
unnamed: E46.1, R111.1
unnamed: E47.2, U16.1
unnamed: E45.2, U16.3
unnamed: D16.C, POWER15.2
unnamed: I2C16.1, R114.2
unnamed: I2C16.3, R113.2
unnamed: D17.A, R115.1
unnamed: E49.2, U17.2
unnamed: E50.1, R117.1
unnamed: E48.1, R119.1
unnamed: E49.1, R118.1
unnamed: E50.2, U17.1
unnamed: E48.2, U17.3
unnamed: D17.C, POWER16.2
unnamed: I2C17.1, R121.2
unnamed: I2C17.3, R120.2
unnamed: D18.A, R122.1
unnamed: E52.2, U18.2
unnamed: E53.1, R124.1
unnamed: E51.1, R126.1
unnamed: E52.1, R125.1
unnamed: E53.2, U18.1
unnamed: E51.2, U18.3
unnamed: D18.C, POWER17.2
unnamed: I2C18.1, R128.2
unnamed: I2C18.3, R127.2
unnamed: D19.A, R129.1
unnamed: E55.2, U19.2
unnamed: E56.1, R131.1
unnamed: E54.1, R133.1
unnamed: E55.1, R132.1
unnamed: E56.2, U19.1
unnamed: E54.2, U19.3
unnamed: D19.C, POWER18.2
unnamed: I2C19.1, R135.2
unnamed: I2C19.3, R134.2
unnamed: D20.A, R136.1
unnamed: E58.2, U20.2
unnamed: E59.1, R138.1
unnamed: E57.1, R140.1
unnamed: E58.1, R139.1
unnamed: E59.2, U20.1
unnamed: E57.2, U20.3
unnamed: D20.C, POWER19.2
unnamed: I2C20.1, R142.2
unnamed: I2C20.3, R141.2
unnamed: D21.A, R143.1
unnamed: E61.2, U21.2
unnamed: E62.1, R145.1
unnamed: E60.1, R147.1
unnamed: E61.1, R146.1
unnamed: E62.2, U21.1
unnamed: E60.2, U21.3
unnamed: D21.C, POWER20.2
unnamed: I2C21.1, R149.2
unnamed: I2C21.3, R148.2
unnamed: D22.A, R150.1
unnamed: E64.2, U22.2
unnamed: E65.1, R152.1
unnamed: E63.1, R154.1
unnamed: E64.1, R153.1
unnamed: E65.2, U22.1
unnamed: E63.2, U22.3
unnamed: D22.C, POWER21.2
unnamed: I2C22.1, R156.2
unnamed: I2C22.3, R155.2
unnamed: D23.A, R157.1
unnamed: E67.2, U23.2
unnamed: E68.1, R159.1
unnamed: E66.1, R161.1
unnamed: E67.1, R160.1
unnamed: E68.2, U23.1
unnamed: E66.2, U23.3
unnamed: D23.C, POWER22.2
unnamed: I2C23.1, R163.2
unnamed: I2C23.3, R162.2
unnamed: D24.A, R164.1
unnamed: E70.2, U24.2
unnamed: E71.1, R166.1
unnamed: E69.1, R168.1
unnamed: E70.1, R167.1
unnamed: E71.2, U24.1
unnamed: E69.2, U24.3
unnamed: D24.C, POWER23.2
SCL: J2.4, J4.4, J5.1, R5.1, U1.6
SCL1: J3.4, J6.4, J8.1, R9.1, U2.6
SCL2: J9.4, J10.4, J12.1, R16.1, U3.6
SCL3: J13.4, J14.4, J16.1, R23.1, U4.6
SCL4: J17.4, J18.4, J20.1, R30.1, U5.6
SCL5: J21.4, J22.4, J24.1, R37.1, U6.6
SCL6: J25.4, J26.4, J28.1, R44.1, U7.6
SCL7: J29.4, J30.4, J32.1, R51.1, U8.6
SCL8: J33.4, J34.4, J36.1, R58.1, U9.6
SCL9: J37.4, J38.4, J40.1, R65.1, U10.6
SCL10: J41.4, J42.4, J44.1, R72.1, U11.6
SCL11: J45.4, J46.4, J48.1, R79.1, U12.6
SCL12: J49.4, J50.4, J52.1, R86.1, U13.6
SCL13: J53.4, J54.4, J56.1, R93.1, U14.6
SCL14: J57.4, J58.4, J60.1, R100.1, U15.6
SCL15: J61.4, J62.4, J64.1, R107.1, U16.6
SCL16: J65.4, J66.4, J68.1, R114.1, U17.6
SCL17: J69.4, J70.4, J72.1, R121.1, U18.6
SCL18: J73.4, J74.4, J76.1, R128.1, U19.6
SCL19: J77.4, J78.4, J80.1, R135.1, U20.6
SCL20: J81.4, J82.4, J84.1, R142.1, U21.6
SCL21: J85.4, J86.4, J88.1, R149.1, U22.6
SCL22: J89.4, J90.4, J92.1, R156.1, U23.6
SCL23: J93.4, J94.4, J96.1, R163.1, U24.6
SDA: J2.3, J4.3, J5.2, R4.1, U1.5
SDA1: J3.3, J6.3, J8.2, R8.1, U2.5
SDA2: J9.3, J10.3, J12.2, R15.1, U3.5
SDA3: J13.3, J14.3, J16.2, R22.1, U4.5
SDA4: J17.3, J18.3, J20.2, R29.1, U5.5
SDA5: J21.3, J22.3, J24.2, R36.1, U6.5
SDA6: J25.3, J26.3, J28.2, R43.1, U7.5
SDA7: J29.3, J30.3, J32.2, R50.1, U8.5
SDA8: J33.3, J34.3, J36.2, R57.1, U9.5
SDA9: J37.3, J38.3, J40.2, R64.1, U10.5
SDA10: J41.3, J42.3, J44.2, R71.1, U11.5
SDA11: J45.3, J46.3, J48.2, R78.1, U12.5
SDA12: J49.3, J50.3, J52.2, R85.1, U13.5
SDA13: J53.3, J54.3, J56.2, R92.1, U14.5
SDA14: J57.3, J58.3, J60.2, R99.1, U15.5
SDA15: J61.3, J62.3, J64.2, R106.1, U16.5
SDA16: J65.3, J66.3, J68.2, R113.1, U17.5
SDA17: J69.3, J70.3, J72.2, R120.1, U18.5
SDA18: J73.3, J74.3, J76.2, R127.1, U19.5
SDA19: J77.3, J78.3, J80.2, R134.1, U20.5
SDA20: J81.3, J82.3, J84.2, R141.1, U21.5
SDA21: J85.3, J86.3, J88.2, R148.1, U22.5
SDA22: J89.3, J90.3, J92.2, R155.1, U23.5
SDA23: J93.3, J94.3, J96.2, R162.1, U24.5
WP: J1.1, R1.2, U1.7, WP.1
WP1: J7.1, R11.2, U2.7, WP1.1
WP2: J11.1, R18.2, U3.7, WP2.1
WP3: J15.1, R25.2, U4.7, WP3.1
WP4: J19.1, R32.2, U5.7, WP4.1
WP5: J23.1, R39.2, U6.7, WP5.1
WP6: J27.1, R46.2, U7.7, WP6.1
WP7: J31.1, R53.2, U8.7, WP7.1
WP8: J35.1, R60.2, U9.7, WP8.1
WP9: J39.1, R67.2, U10.7, WP9.1
WP10: J43.1, R74.2, U11.7, WP10.1
WP11: J47.1, R81.2, U12.7, WP11.1
WP12: J51.1, R88.2, U13.7, WP12.1
WP13: J55.1, R95.2, U14.7, WP13.1
WP14: J59.1, R102.2, U15.7, WP14.1
WP15: J63.1, R109.2, U16.7, WP15.1
WP16: J67.1, R116.2, U17.7, WP16.1
WP17: J71.1, R123.2, U18.7, WP17.1
WP18: J75.1, R130.2, U19.7, WP18.1
WP19: J79.1, R137.2, U20.7, WP19.1
WP20: J83.1, R144.2, U21.7, WP20.1
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

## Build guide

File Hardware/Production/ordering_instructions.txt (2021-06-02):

panel size, 169x117mm
PCB thickness, 1.6mm
number of layers, 2
soldermask color, Red
silkscreen color, White
oz copper, 1oz
finish, HASL lead free
stencils, top
pcs per panel, 24
min trace width, 0.2032mm / 0.0080in
min drill size, 0.3048mm / 0.0120in

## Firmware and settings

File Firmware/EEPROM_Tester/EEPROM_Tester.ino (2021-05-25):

/*
  A simple test for our Qwiic EEPROM board.
*/

#include <Wire.h>

#include "SparkFun_External_EEPROM.h" // Click here to get the library: http://librarymanager/All#SparkFun_External_EEPROM
ExternalEEPROM myMem;

const int LED = 13;

void setup()
{
  Serial.begin(115200);
  Serial.println("Qwiic EEPROM Tester");

  pinMode(LED, OUTPUT);

  Wire.begin();
}

void loop()
{
  if (myMem.begin() == true)
  {
    Serial.println("EEPROM Detected");
    digitalWrite(LED, HIGH);
  }
  else
  {
    Serial.println("Nothing detected!");
    digitalWrite(LED, LOW);
  }
  delay(100);

}

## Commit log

2021-05-26 Add datasheet, make sure all parts are from SF libraries
    [Qwiic EEPROM.brd, Qwiic EEPROM.sch]
2021-05-26 Hardware updates
    Schematic symbols from current SF libs
    Added mounting holes
    re-routing
    Update 3.3V rail width
    [Qwiic EEPROM.brd, Qwiic EEPROM.sch]
2021-05-26 Vectorize labels
    [Qwiic EEPROM.brd, Qwiic EEPROM.sch]
2021-05-28 Design review changes
    Schematic:
    * Added Vcc range for EEPROM IC
    * Updated notes for power led and address jumpers
    * Got rid of legacy font
    * Replaced pullup/pulldown resistors R1, R2, R6, R7 to 100k
    Board:
    * Weird tRestrict on GND pad of EEPROM IC --> moved via around to avoid DRC errors
    * Moved "PWR" label underneath the LED
    * Moved "I2C" label so that it touches the silk of the jumper above it
    * Re-routed 3.3V trace so that it does not run under the EEPROM IC
    * Increased size of fiducials
    * Made vias all the same size
    * Added prod-id to the EEPROM IC
    [Qwiic EEPROM.brd, Qwiic EEPROM.sch]
2021-06-02 QC Double-check
    [Qwiic EEPROM.sch]
2021-06-02 QC Double-check: update silkscreen
    [Qwiic EEPROM.brd]
2021-06-02 Update WP buzzard label
    [Qwiic EEPROM.brd]
2021-06-02 Update Qwiic EEPROM.brd
    [Qwiic EEPROM.brd]
2022-02-28 Update EEPROM part number to CAT24C51 and re-generate schematic
    [Qwiic EEPROM.brd, Qwiic EEPROM.sch]

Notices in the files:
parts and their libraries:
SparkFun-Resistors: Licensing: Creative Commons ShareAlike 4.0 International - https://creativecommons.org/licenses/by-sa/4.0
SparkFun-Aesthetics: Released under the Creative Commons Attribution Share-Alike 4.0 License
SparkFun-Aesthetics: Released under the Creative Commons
